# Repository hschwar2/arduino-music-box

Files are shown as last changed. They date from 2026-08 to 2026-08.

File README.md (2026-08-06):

# Arduino Interactive Music Box & Custom PCB Shield

A complete embedded hardware and firmware system built around the ATmega328P (Arduino Uno R3) platform. This project features a custom-designed 2-layer PCB shield, real-time song switching via dynamic loop interrupts, tone-synced 24-bit RGB lighting, diode-OR hardware logic, and dynamic potentiometer audio scaling

Designed, routed, and documented using **KiCad 9.0**.

---

## Key Technical Features

* **Custom 2-Layer PCB Shield:** Designed a custom PCB in KiCad that plugs directly onto an Arduino Uno R3, featuring optimized ground pours, clean trace routing, and through-hole component footprints.
* **Diode-OR Hardware Interrupt Circuit:** Bypasses hardware pin constraints on the ATmega328P by multiplexing 4 active-high pushbuttons into a single interrupt pin (`Digital Pin 2`) using 1N4148 switching diodes.
* **Real-Time Input Polling:** Uses analog pins (`A2–A5`) as digital inputs with 10k Ohm pull-down resistors to instantly decode button presses after triggering the ISR.
* **Dynamic Song Interruption:** Firmware regularly checks an interrupt flag during song playback loops to provide instantaneous song cancellation and input switching.
* **Tone-to-Color RGB Mapping:** Embedded C++ data structures map 27 chromatic note frequencies to 24-bit RGB values, creating custom visual lighting effects synced to audio pitch.
* **Analog Volume & Brightness Control:** Potentiometer voltage divider dynamically scales piezo speaker drive voltage and audio output levels.

---

## Hardware Architecture & Design

### Breadboard Concept
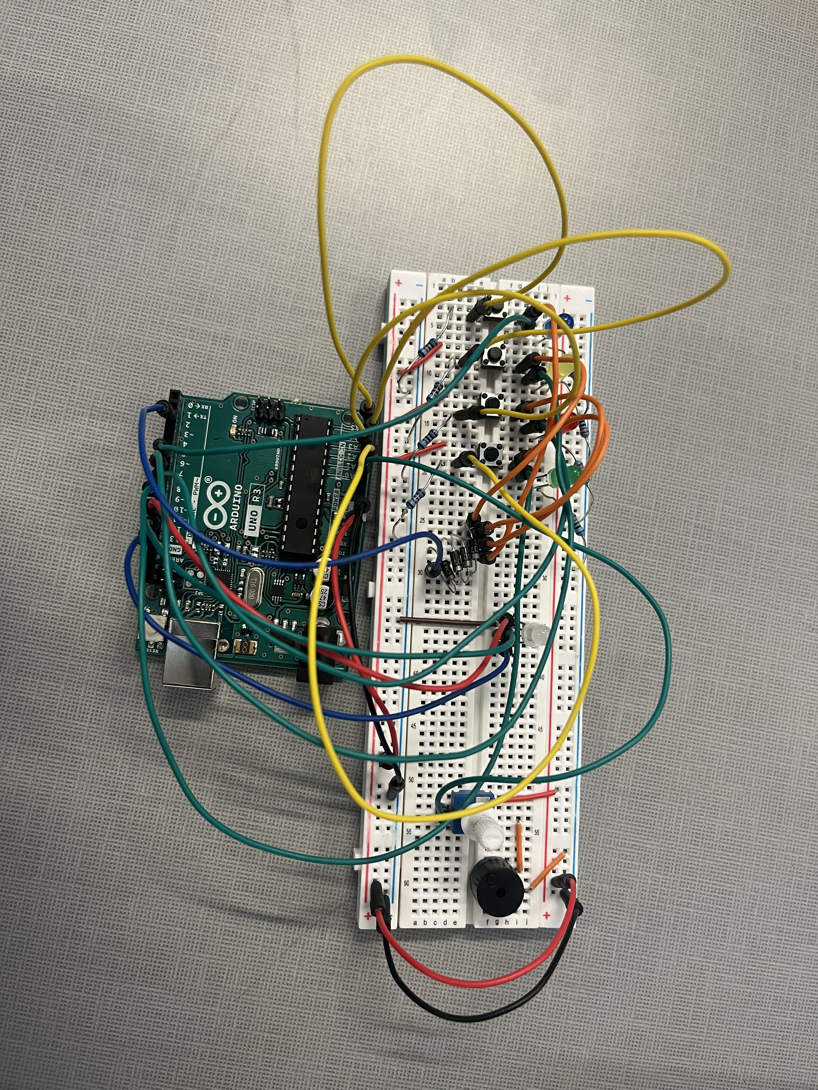
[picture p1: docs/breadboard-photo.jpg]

### Schematic Capture
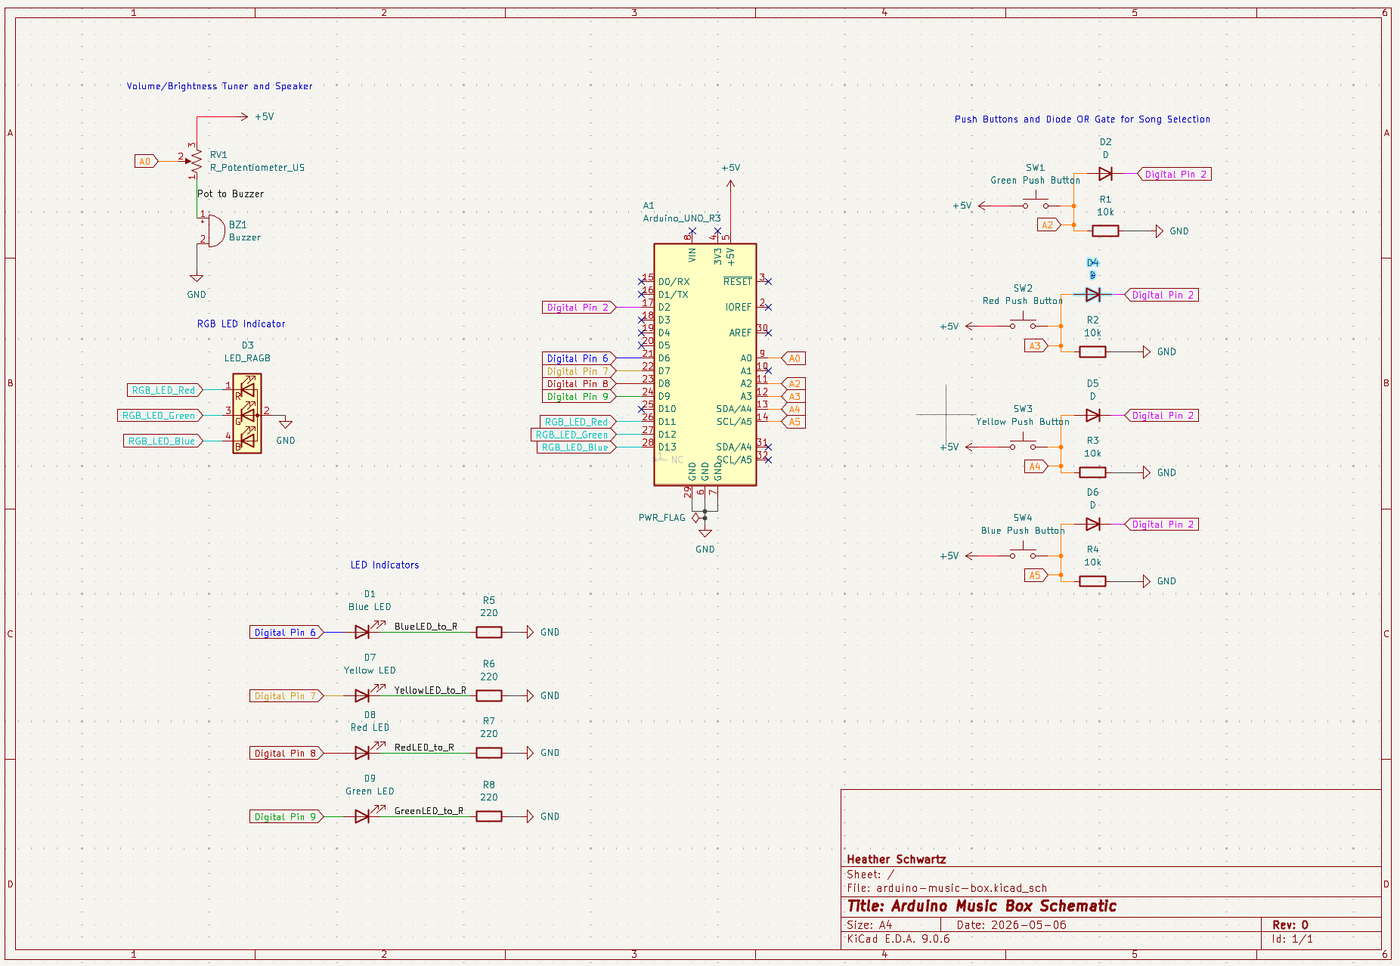
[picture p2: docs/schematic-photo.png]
Arduino Music Box Schematic


### 3D PCB Layout
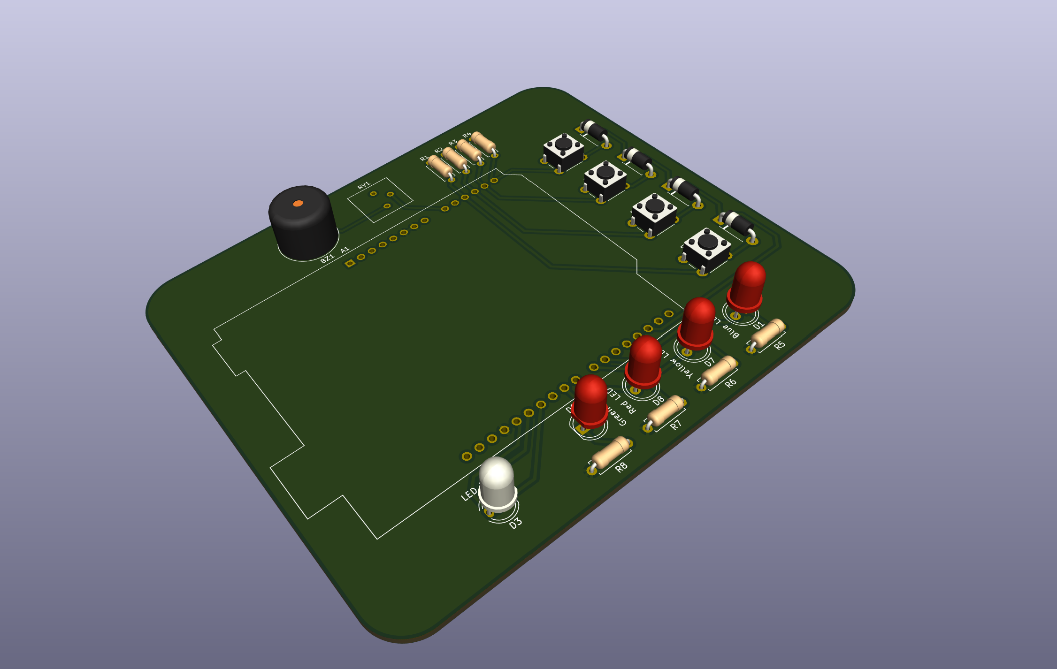
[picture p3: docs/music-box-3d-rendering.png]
Arduino Music Box 3D PCB Render


* **[View KiCad 9.0 Project Files](hardware/)**

---

## Pin Mapping & Component Specification

| Component | Arduino Pin | Circuit Function |
| :--- | :--- | :--- |
| **Diode-OR Interrupt Line** | `Digital Pin 2 (INT0)` | Common hardware interrupt trigger from all 4 buttons |
| **Blue Active LED** | `Digital Pin 6` | Status indicator (220 Ohms current limiting) |
| **Yellow Active LED** | `Digital Pin 7` | Status indicator (220 Ohms current limiting) |
| **Red Active LED** | `Digital Pin 8` | Status indicator (220 Ohms current limiting) |
| **Green Active LED** | `Digital Pin 9` | Status indicator (220 Ohms current limiting) |
| **RGB LED (Red/Green/Blue)** | `Digital Pins 11, 12, 13` | Frequency-synced chromatic lighting display |
| **Potentiometer & Buzzer** | `Analog Pin A0` | Wiper analog reference and piezo speaker driver |
| **Green Pushbutton Sense** | `Analog Pin A2` | Song 1 selection input |
| **Red Pushbutton Sense** | `Analog Pin A3` | Song 2 selection input |
| **Yellow Pushbutton Sense** | `Analog Pin A4` | Song 3 selection input |
| **Blue Pushbutton Sense** | `Analog Pin A5` | Song 4 selection input |

---

## Circuit & PCB Engineering Highlights

### Diode-OR Hardware Interrupt
Standard ATmega328P microcontrollers feature only two external hardware interrupt pins (`INT0` on Pin 2 and `INT1` on Pin 3). To handle 4 independent pushbutton inputs without continuous software polling, four 1N4148 diodes form a diode-OR logic gate:

1. Pressing any button routes current through its respective diode to pull `Digital Pin 2` `HIGH`.
2. An **Interrupt Service Routine (ISR)** triggers on the rising edge.
3. The MCU polls lines `A2–A5` to identify which specific button was pressed.

### PCB Layout Considerations
* **Board Dimensions:** Form-factor matches standard Arduino Uno R3 header dimensions ($68.6\text{ mm} \times 53.4\text{ mm}$).
* **Ground Pours:** Top and bottom layers utilize solid Ground Planes ($\text{GND}$) for return paths and noise reduction.
* **Trace Parameters:** Signal traces routed at 0.25 mm width; power rails ($5\text{V}$, $\text{GND}$) widened to 0.5 mm for power delivery.

---

## Firmware Architecture

The C++ firmware is built using custom structs that bundle note frequencies, durations, and RGB color vectors:

```cpp
struct Note {
  int frequency;  // Hz
  int duration;   // ms
  byte red;       // 0-255 PWM
  byte green;     // 0-255 PWM
  byte blue;      // 0-255 PWM
};

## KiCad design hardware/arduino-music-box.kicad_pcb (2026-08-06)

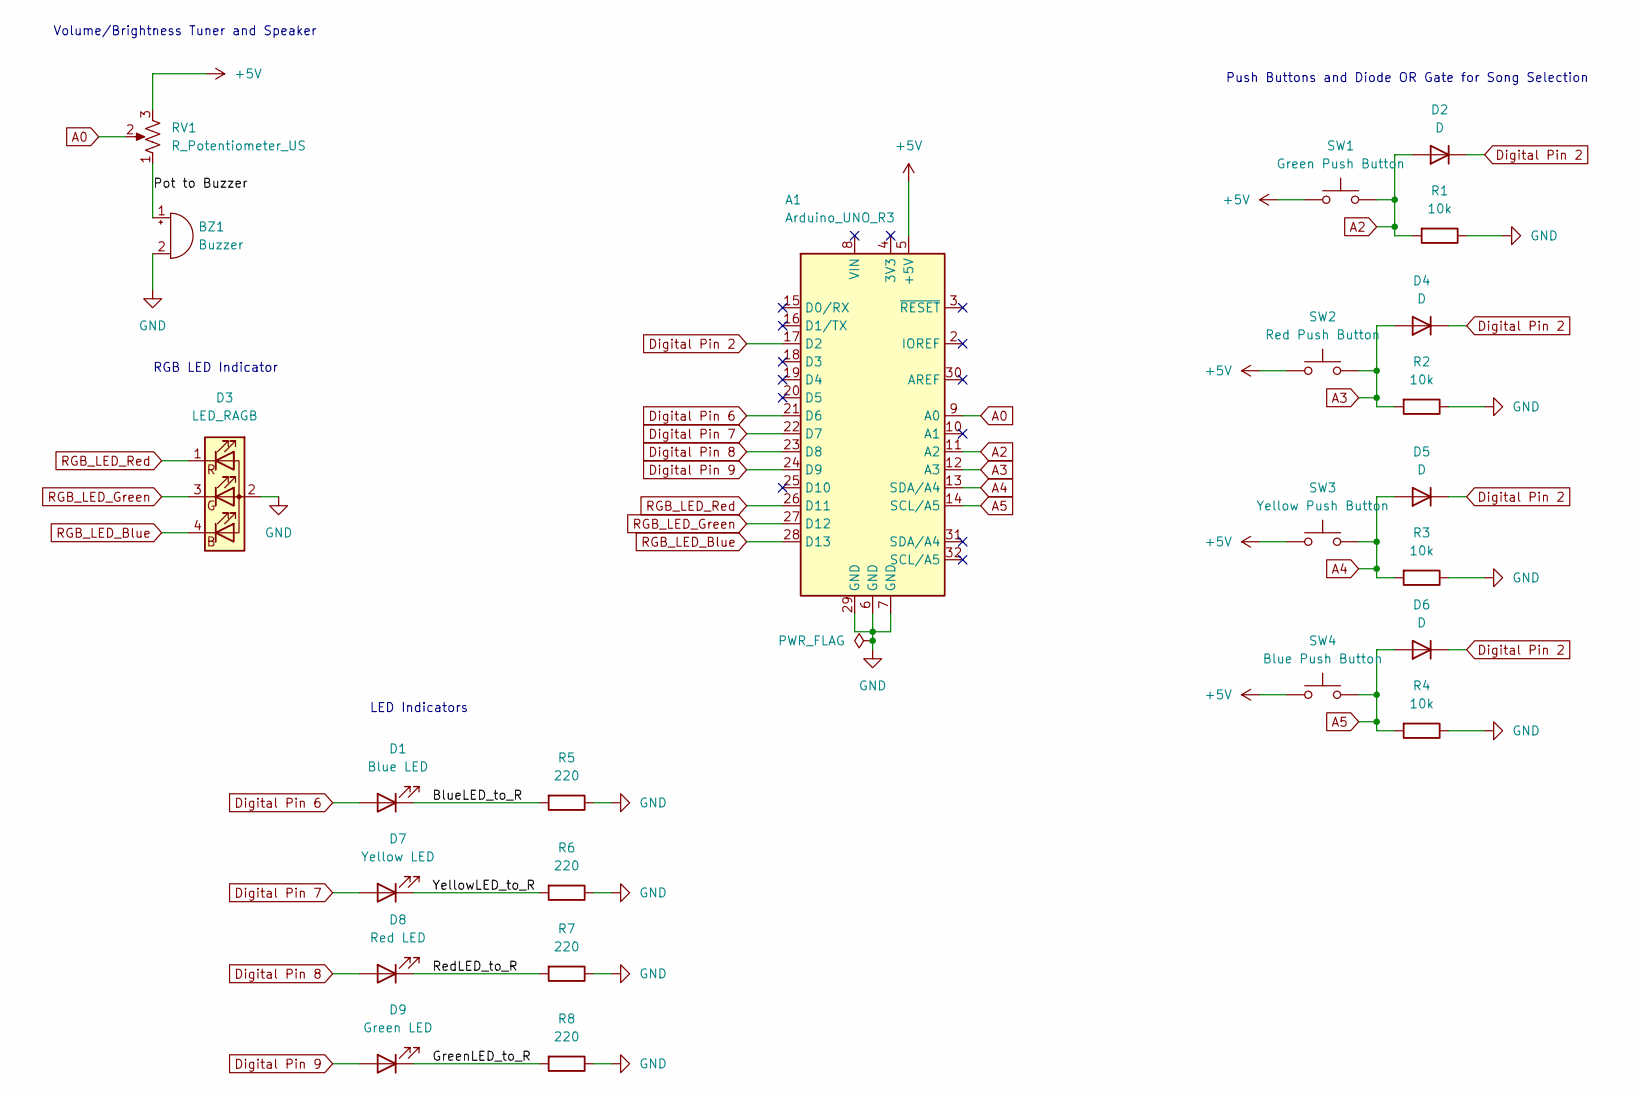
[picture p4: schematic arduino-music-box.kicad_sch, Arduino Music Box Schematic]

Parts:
A1: Arduino_UNO_R3
BZ1: Buzzer; Buzzer_12x9.5RM7.6
D1: Blue LED; LED_D5.0mm
D2, D4, D5, D6: D; D_DO-41_SOD81_P7.62mm_Horizontal
D3: LED_RAGB; LED_D5.0mm-4_RGB
D7: Yellow LED; LED_D5.0mm
D8: Red LED; LED_D5.0mm
D9: Green LED; LED_D5.0mm
R1, R2, R3, R4: 10k; R_Axial_DIN0207_L6.3mm_D2.5mm_P7.62mm_Horizontal
R5, R6, R7, R8: 220; R_Axial_DIN0207_L6.3mm_D2.5mm_P7.62mm_Horizontal
RV1: R_Potentiometer_US; Potentiometer_Bourns_3386P_Vertical
SW1: Green Push Button; SW_PUSH_6mm
SW2: Red Push Button; SW_PUSH_6mm
SW3: Yellow Push Button; SW_PUSH_6mm
SW4: Blue Push Button; SW_PUSH_6mm

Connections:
+5V: A1.5 (+5V), RV1.3, SW1.1, SW2.1, SW3.1, SW4.1
/BlueLED_to_R: D1.1 (K), R5.2
/GreenLED_to_R: D9.1 (K), R8.2
/Pot to Buzzer: BZ1.1 (+), RV1.1
/RedLED_to_R: D8.1 (K), R7.2
/YellowLED_to_R: D7.1 (K), R6.2
A0: A1.9 (A0), RV1.2
A2: A1.11 (A2), D2.2 (A), R1.2, SW1.2
A3: A1.12 (A3), D4.2 (A), R2.2, SW2.2
A4: A1.13 (SDA/A4), D5.2 (A), R3.2, SW3.2
A5: A1.14 (SCL/A5), D6.2 (A), R4.2, SW4.2
Digital Pin 2: A1.17 (D2), D2.1 (K), D4.1 (K), D5.1 (K), D6.1 (K)
Digital Pin 6: A1.21 (D6), D1.2 (A)
Digital Pin 7: A1.22 (D7), D7.2 (A)
Digital Pin 8: A1.23 (D8), D8.2 (A)
Digital Pin 9: A1.24 (D9), D9.2 (A)
GND: A1.6 (GND), A1.7 (GND), A1.29 (GND), BZ1.2 (-), D3.2 (A), R1.1, R2.1, R3.1, R4.1, R5.1, R6.1, R7.1, R8.1
RGB_LED_Blue: A1.28 (D13), D3.4 (BK)
RGB_LED_Green: A1.27 (D12), D3.3 (GK)
RGB_LED_Red: A1.26 (D11), D3.1 (RK)

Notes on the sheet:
RGB LED Indicator
Volume/Brightness Tuner and Speaker
Push Buttons and Diode OR Gate for Song Selection
LED Indicators

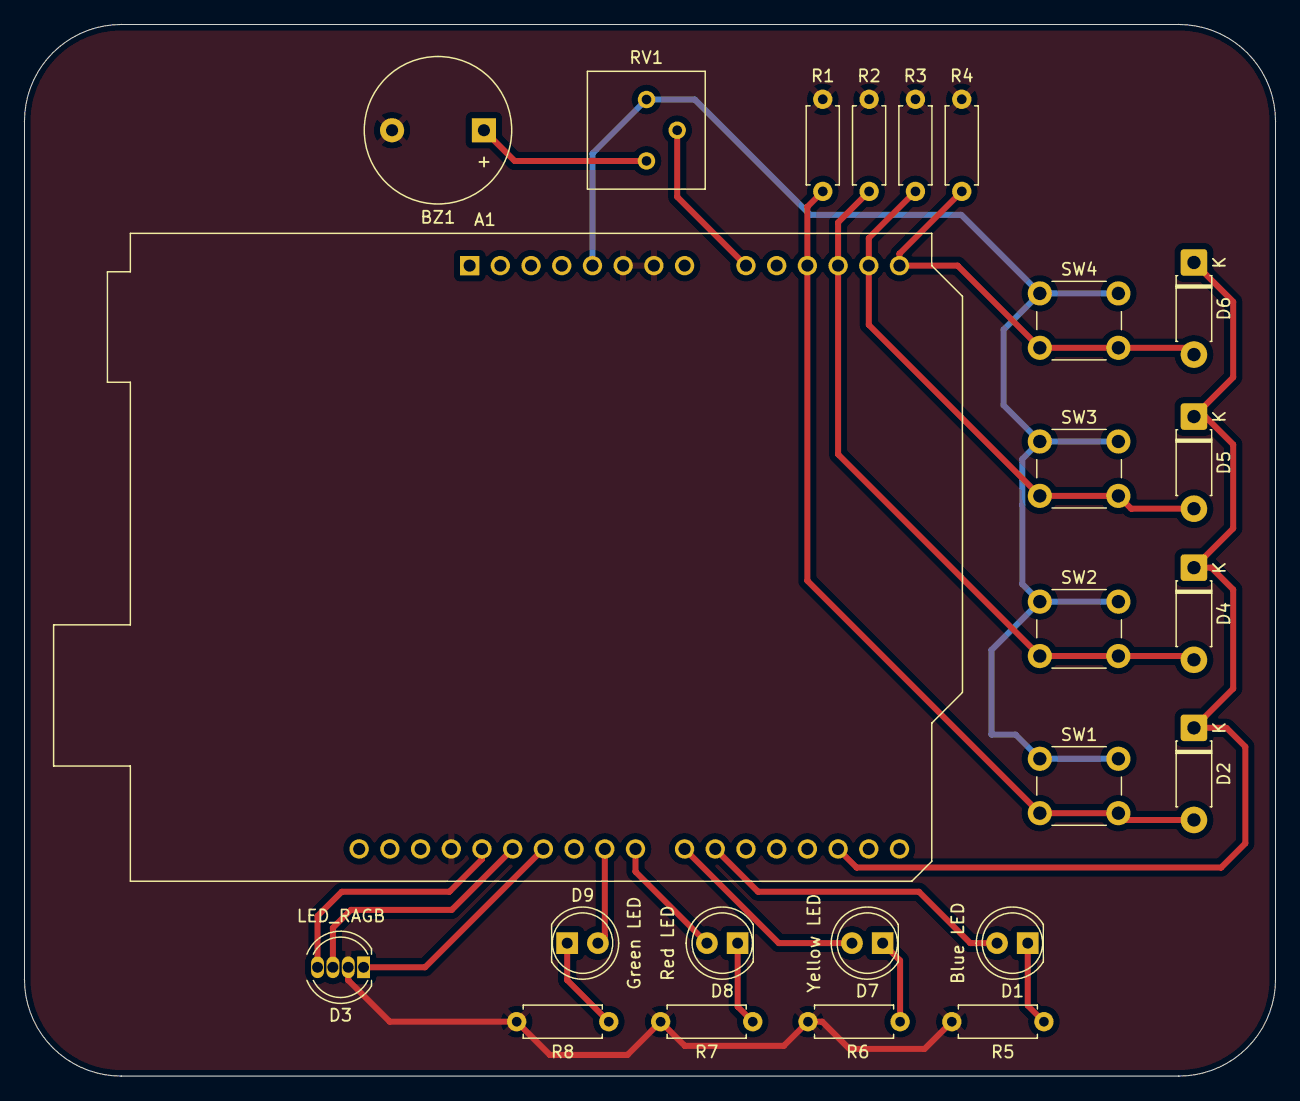
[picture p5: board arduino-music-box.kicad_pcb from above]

Board: 2 copper layers, 103.5 x 87.0 mm, 24 parts (0 on the bottom side), 20 nets.

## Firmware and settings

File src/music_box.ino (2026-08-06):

//------------ PINS -----------------
const int kBlueButtonPin = A5;
const int kYellowButtonPin = A4;
const int kRedButtonPin = A3;
const int kGreenButtonPin = A2;


const int kBlueLEDPin = 6;
const int kYellowLEDPin = 7;
const int kRedLEDPin = 8;
const int kGreenLEDPin = 9;


const int kBuzzerPotPin = A0;
const int kButtonPressedPin = 2;


const int krgbRedPin = 11;
const int krgbBluePin = 13;
const int krgbGreenPin = 12;


volatile bool buttonStatusTrue = false;
volatile int whichButtonPressed = -1; //1  = blue, 2 = yellow, 3 = red, 4 = green (-1 is invalid)


//structs - these were not covered in class, but after research it was decided that these would be best
//to store a frequency and associated color
struct Note {
  int freq;
  int r;
  int g;
  int b;


};
// to store the note and associated duration of note
struct MelodyStep{
  Note note;
  int duration;


};


//FREQUENCY TO NOTE TRANSLATION
// Note frequencies (Hz) with associated colors- full chromatic scale
// index 0 = frequency, index 1 = r, index 2 = g, index 3 = b
const Note kNoteRest = {0, 0, 0, 0};
const Note kNoteC4   = {262, 255, 0, 0};     // Red
const Note kNoteCS4  = {277, 150, 20, 0};    // Dark Red
const Note kNoteD4   = {294, 255, 128, 0};   // Orange
const Note kNoteDS4  = {311, 150, 100, 0};   // Gold
const Note kNoteE4   = {330, 255, 255, 0};   // Bright Yellow
const Note kNoteF4   = {349, 0, 255, 0};     // Green
const Note kNoteFS4  = {370, 0, 150, 70};    // Pine Green
const Note kNoteG4   = {392, 0, 255, 255};   // Cyan
const Note kNoteGS4  = {415, 0, 100, 200};   // Medium Blue
const Note kNoteGSharp4 = {415, 0, 100, 200};// (Match GS4)
const Note kNoteA4   = {440, 0, 0, 255};     // Royal Blue
const Note kNoteAS4  = {466, 100, 0, 200};   // Deep Purple
const Note kNoteB4   = {494, 255, 0, 255};   // Magenta
const Note kNoteC5   = {523, 255, 100, 100}; // Coral/Salmon
const Note kNoteCS5  = {554, 200, 50, 100};  
const Note kNoteD5   = {587, 255, 200, 100}; // Peach
const Note kNoteDS5  = {622, 119, 255, 53};  // Neon Green
const Note kNoteE5   = {659, 255, 255, 150}; // Pale Yellow
const Note kNoteF5   = {698, 150, 255, 255}; // Pale Blue
const Note kNoteFS5  = {740, 0, 180, 120};   // Seafoam Green
const Note kNoteG5   = {784, 180, 150, 255}; // Lavender
const Note kNoteGS5  = {831, 208, 188, 255}; // Periwinkle
const Note kNoteA5   = {880, 195, 255, 188}; // Mint Green
const Note kNoteAS5  = {932, 29, 71, 24};    // Forest Green
const Note kNoteB5   = {988, 145, 255, 253}; // Aquamarine
const Note kNoteC6   = {1047, 233, 255, 169}; // Lime Green
const Note kNoteD6   = {1175, 145, 3, 87};    // Maroon
const Note kNoteE6   = {1319, 180, 126, 240}; // Violet
const Note kNoteF6   = {1397, 255, 100, 0};   // Orange
const Note kNoteG6   = {1568, 255, 243, 0};   // Gold


// SONGS - melody struct array of notes and associated frequencies
// Harry Potter Theme (Hedwig's Theme)
MelodyStep kMelodyHarryPotter[] = {
  {kNoteB4, 400}, {kNoteE5, 600}, {kNoteG5, 200}, {kNoteFS5, 400}, {kNoteE5, 800},
  {kNoteB5, 400}, {kNoteA5, 1200},
  {kNoteFS5, 1200},
  {kNoteE5, 600}, {kNoteG5, 200}, {kNoteFS5, 400}, {kNoteDS5, 800},
  {kNoteF5, 400}, {kNoteB4, 1600}}; // 14 long


// Imperial March
MelodyStep kMelodyImperialMarch[]= {
  {kNoteA4, 500}, {kNoteA4, 500}, {kNoteA4, 500}, {kNoteF4, 350}, {kNoteC5, 150},
  {kNoteA4, 500}, {kNoteF4, 350}, {kNoteC5, 150}, {kNoteA4, 650},
  {kNoteE5, 500}, {kNoteE5, 500}, {kNoteE5, 500}, {kNoteF5, 350}, {kNoteC5, 150},
  {kNoteGSharp4, 500}, {kNoteF4, 350}, {kNoteC5, 150}, {kNoteA4, 650}}; //18 long


// The Godfather Love Theme
MelodyStep kMelodyTheGodfather[] = {
  {kNoteE4, 375}, {kNoteA4, 375}, {kNoteC5, 375}, //1
  {kNoteB4, 375}, {kNoteA4, 375}, {kNoteC5, 375}, {kNoteA4, 375}, {kNoteB4, 375}, {kNoteA4, 375}, {kNoteF4, 375}, {kNoteG4, 375},
  {kNoteE4, 1500}, {kNoteE4, 375}, {kNoteA4, 375}, {kNoteC5, 375},
  {kNoteB4, 375}, {kNoteA4, 375}, {kNoteC5, 375}, {kNoteA4, 375}, {kNoteC5, 375}, {kNoteA4, 375}, {kNoteE4, 375}, {kNoteDS4, 375},
  {kNoteD4, 1500}, {kNoteD4, 375}, {kNoteF4, 375} // Ends at note 26
};


// Never Gonna Give You Up
MelodyStep kMelodyNeverGonnaGiveYouUp[] = {
  {kNoteD5, 789}, {kNoteE5, 789}, {kNoteA4, 526},
  {kNoteE5, 789}, {kNoteFS5, 789}, {kNoteA5, 131}, {kNoteG5, 131}, {kNoteFS5, 263},
  {kNoteD5, 789}, {kNoteE5, 789}, {kNoteA4, 1052},
  {kNoteA4, 131}, {kNoteA4, 131}, {kNoteB4, 131}, {kNoteD5, 263}, {kNoteD5, 131},
  {kNoteD5, 789}, {kNoteE5, 789}, {kNoteA4, 526},
  {kNoteE5, 789}, {kNoteFS5, 789}, {kNoteA5, 131}, {kNoteG5, 131}, {kNoteFS5, 263},
  {kNoteD5, 789}, {kNoteE5, 789}, {kNoteA4, 1052},
  {kNoteA4, 131}, {kNoteA4, 131}, {kNoteB4, 131} // Ends at note 30
};


MelodyStep kMelodyMario[] = {
  {kNoteE5, 125}, {kNoteE5, 125}, {kNoteRest, 125}, {kNoteE5, 125}, {kNoteRest, 125}, {kNoteC5, 125}, {kNoteE5, 125}, {kNoteRest, 125},
  {kNoteG5, 125}, {kNoteRest, 375}, {kNoteG4, 125}, {kNoteRest, 375},
  {kNoteC5, 250}, {kNoteG4, 250}, {kNoteE4, 250}, {kNoteA4, 250}, {kNoteB4, 250}, {kNoteAS4, 125}, {kNoteA4, 250},
  {kNoteG4, 150}, {kNoteE5, 150}, {kNoteG5, 150}, {kNoteA5, 250}, {kNoteF5, 125}, {kNoteG5, 125},
  {kNoteE5, 250}, {kNoteC5, 125}, {kNoteD5, 125}, {kNoteB4, 250}
}; // 29 steps


MelodyStep kMelodyStarWarsTheme[] = {
  {kNoteG4, 500}, {kNoteD5, 500}, {kNoteC5, 150}, {kNoteB4, 150}, {kNoteA4, 150}, {kNoteG5, 500}, {kNoteD5, 250},
  {kNoteC5, 150}, {kNoteB4, 150}, {kNoteA4, 150}, {kNoteG5, 500}, {kNoteD5, 250}, {kNoteC5, 150}, {kNoteB4, 150}, {kNoteC5, 150},
  {kNoteA4, 500}, {kNoteG4, 500}, {kNoteD5, 500}, {kNoteC5, 150}, {kNoteB4, 150}, {kNoteA4, 150}, {kNoteG5, 500}, {kNoteD5, 250},
  {kNoteC5, 150}, {kNoteB4, 150}, {kNoteA4, 150}, {kNoteG5, 500}
}; // 27 steps


void setup() {
  // put your setup code here, to run once:
  Serial.begin(9600);
  Serial.println("Serial Monitor Initialized");


  pinMode(kBlueLEDPin, OUTPUT);
  pinMode(kYellowLEDPin, OUTPUT);
  pinMode(kRedLEDPin, OUTPUT);
  pinMode(kGreenLEDPin, OUTPUT);


  pinMode(krgbRedPin, OUTPUT);
  pinMode(krgbBluePin, OUTPUT);
  pinMode(krgbGreenPin, OUTPUT);


  attachInterrupt(digitalPinToInterrupt(kButtonPressedPin), buttonPressed, RISING);


}


void loop() {
  delay(100);


  if(buttonStatusTrue){
    //making false so it resets after
      buttonStatusTrue = false;  


    //pulling all LEDS low
      pullAllLedsLow();


    //finding which button was pressed
    // finding which button was pressed: 1 = blue; 2 = yellow; 3 = red; 4 = green
    // calls functions associated with button press (setting led to high and playing song   associated with button)


    switch(whichButtonPressed){
      case 1:
        digitalWrite(kBlueLEDPin, HIGH);
        playMelody(kMelodyStarWarsTheme, 27);
        delay(50);
      break;


      case 2:
        digitalWrite(kYellowLEDPin, HIGH);
        playMelody(kMelodyMario, 29);
        delay(50);
      break;


      case 3:
        digitalWrite(kRedLEDPin, HIGH);
        playMelody(kMelodyTheGodfather, 26);
        delay(50);
      break;


      case 4:
        digitalWrite(kGreenLEDPin, HIGH);
        playMelody(kMelodyNeverGonnaGiveYouUp, 30);
        delay(50);


      case -1:
        Serial.println("no button found :(");
      break;


      default:
        Serial.println("How did you get here?");
      break;
    }


  }
}


/*This function will analog read each color button to see which one was pressed, returning the int associated with that color. If none were pressed, returning -1*/
int pollButtonPressed(){
  if(analogRead(kBlueButtonPin) > 500){
    return 1;
  }
  else if (analogRead(kYellowButtonPin) > 500){
    return 2;
  }
  else if(analogRead(kRedButtonPin) > 500){
    return 3;
  }
  else if(analogRead(kGreenButtonPin) > 500){
    return 4;
  }
  else
    return -1;


}
/*This function pulls all of the leds to low as a reset, so none are bright at the same time*/
void pullAllLedsLow(){
  digitalWrite(kBlueLEDPin, LOW);
  digitalWrite(kYellowLEDPin, LOW);
  digitalWrite(kRedLEDPin, LOW);
  digitalWrite(kGreenLEDPin, LOW);


}
/*This function will set the volatile boolean buttonStatusTrue to true and poll which button was pressed, changing the volatile int whichButtonPressed*/
void buttonPressed(){
  buttonStatusTrue = true;
  whichButtonPressed = pollButtonPressed();


}
/*This function will run through the melody step arrays and run the song passed through as an argument. If the button is pressed, it breaks out of the for loop and stops playing the current song.*/
void playMelody(MelodyStep melody[], int lengthSong) {
    for (int i = 0; i < lengthSong; i++) {
      if(buttonStatusTrue){
        break;
      }
      //getting current note and duration
        Note currentNote = melody[i].note;
        int duration = melody[i].duration;
        //displaying rgb color to the led
          writeColor(currentNote.r, currentNote.g, currentNote.b);


        //playing melody
        if (currentNote.freq == kNoteRest.freq) {
            noTone(kBuzzerPotPin);
            delay(duration);
        } else {
            tone(kBuzzerPotPin, currentNote.freq, duration);
            delay(duration + 20);
        }
    }
    noTone(kBuzzerPotPin);
}


// RGB LED functions
void writeColor(int redPWM, int greenPWM, int bluePWM){
  //polling brightness of rgb led
    int voltage = analogRead(kBuzzerPotPin);
    float pwmVal = map(voltage, 0, 1023, 0, 255);
    float percentPWM = 1-pwmVal/255.;


  //Serial.println(percentPwm);
    Serial.println(percentPWM);


//writing to pins
  analogWrite(krgbRedPin, redPWM*percentPWM);
  analogWrite(krgbBluePin, bluePWM*percentPWM);
  analogWrite(krgbGreenPin, greenPWM*percentPWM);
}

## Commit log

2026-08-06 Add music box functionality with melodies and controls
    This file contains the implementation of a music box with various melodies and button controls.
2026-08-06 Create README for Arduino music box project
    Added a detailed README for the Arduino Multi-Button Interactive Music Box project, including technical highlights, hardware architecture, circuit diagrams, pin mapping, and software design.
2026-08-06 Update schematic image reference in README
2026-08-06 Revise README with project details and images
    Updated project title and enhanced technical details, including key features and hardware architecture. Added images for schematic and PCB layout.
2026-08-06 Update resistor notation in README.md
    Replaced '10kΩ' with '10k Ohm' and '220Ω' with '220 Ohms' for consistency in terminology.
2026-08-06 Update PCB shield description in README
    Removed specific pitch mention for component footprints in PCB shield description.
2026-08-06 Update schematic image in README
